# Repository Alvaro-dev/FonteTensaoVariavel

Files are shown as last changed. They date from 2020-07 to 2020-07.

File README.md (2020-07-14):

# Fonte Tensão 12V
Projeto de uma Fonte de Tensão Variável de 3V a 12V, desenvolvido para a disciplina de Eletrônica para Computação, ministrada pelo Professor Dr. Eduardo do Valle Simões
# Circuito Falstad
<a href = "http://tinyurl.com/yclddzmd"> Circuito Falstad</a>
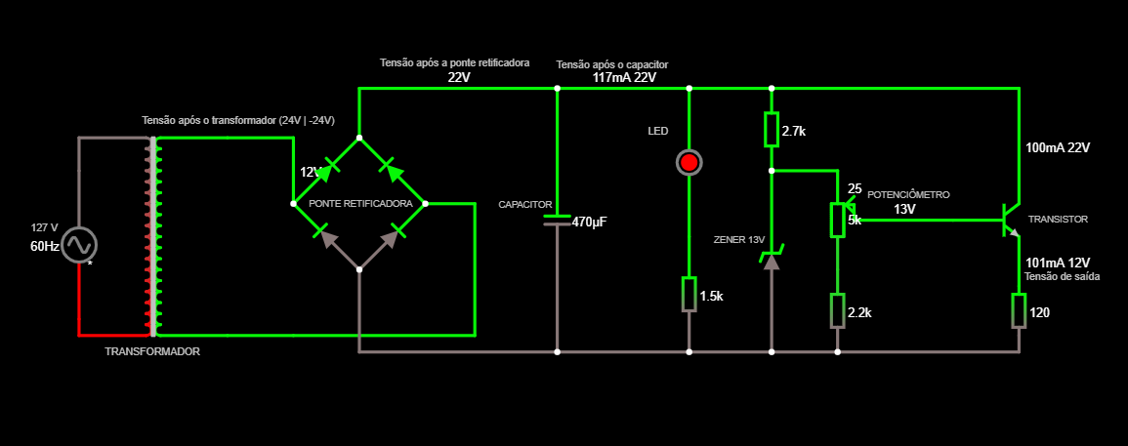
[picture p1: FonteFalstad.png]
Falstad

# Circuito EAGLE

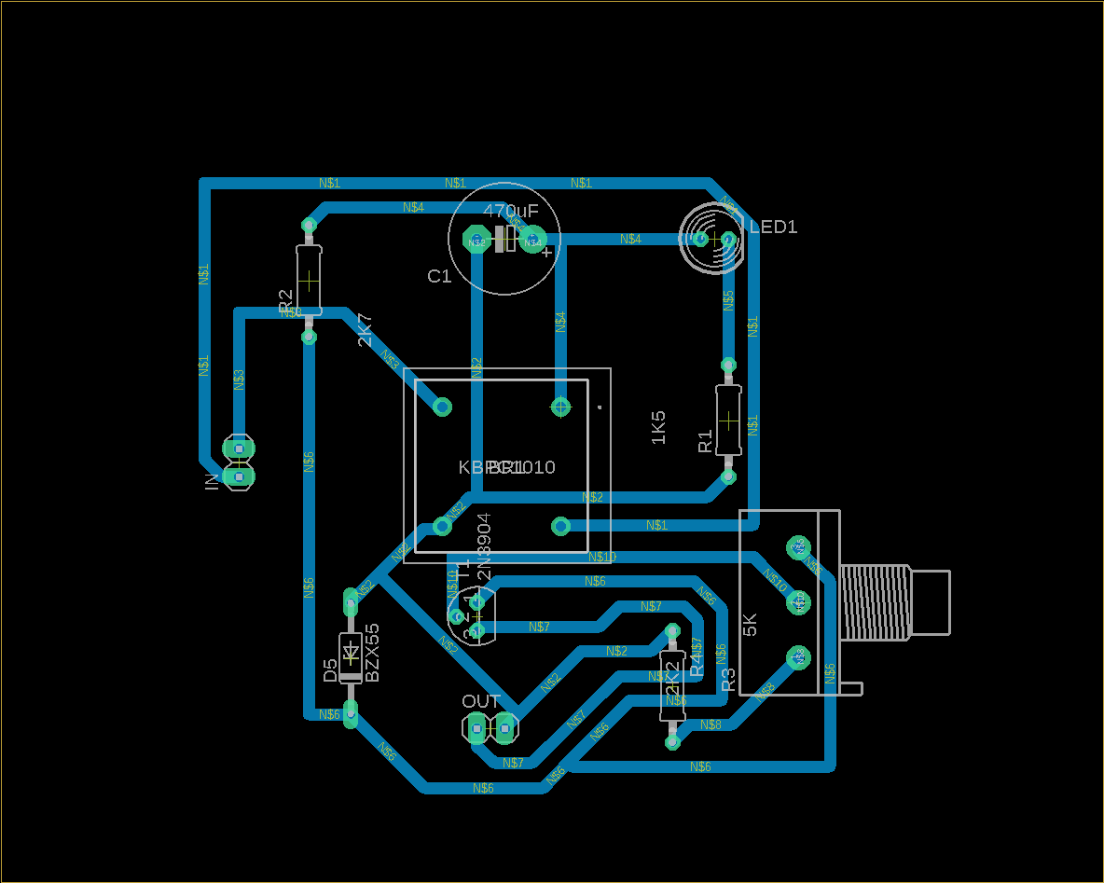
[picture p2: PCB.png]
PCB


<a href = "https://drive.google.com/file/d/1tgSCFVqVofuXs6VpP3hKhitnwWkWix8T/view?usp=sharing"> Vídeo Explicativo</a>

# Esquemático EAGLE
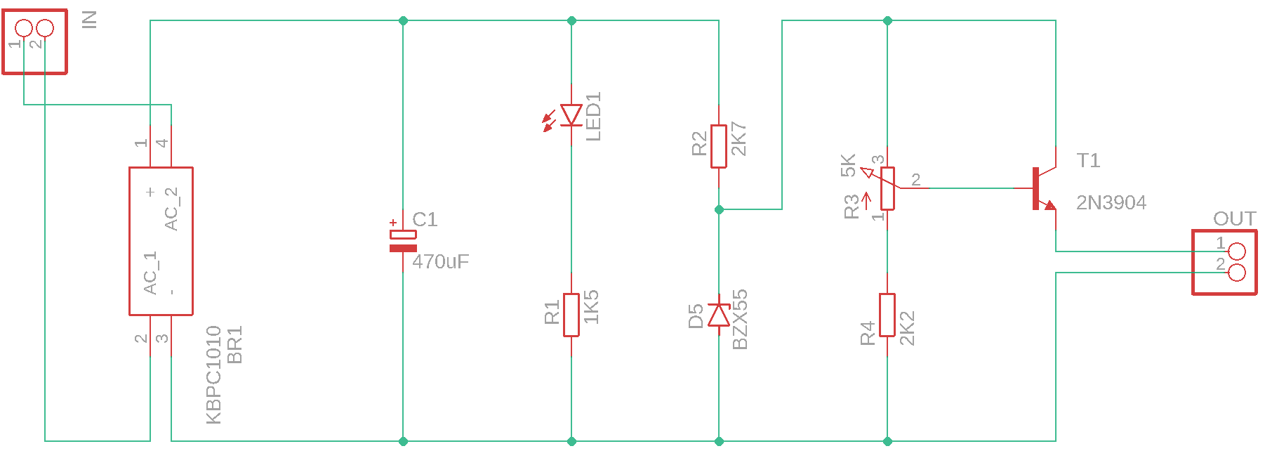
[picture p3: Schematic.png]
Schematic


## Conversor Corrente Alternada de Alta Tensão para Corrente Alternada de Baixa Tensão
Ao usar um transformador de 127V AC para 24V AC, com a razão descrita abaixo, a tensão do circuito, fica adequada aos componentes usados na fonte, que são mais sensíveis a valores altos de tensão e suas variações. Quando há variação de fluxo na corrente primária (127V), na parte secundária, é gerada uma corrente induzida com um potencial elétrico menor (24V). O intervalo de oscilação sai de 127V a -127V para 24V a -24V. A razão obtida na fórmula abaixo, auxiliou a resolução da problemática no Falstad, para conseguir ajustar a tensão secundária do transformador.

Transformador

## Conversor Corrente Alternada para Corrente Contínua
Como estamos lidando com uma corrente alternada (24V a -24V), é necessário uma estratégia para converter desse tipo de corrente elétrica para contínua, para o funcionamento adequado da fonte. Assim, usa-se uma ponte retificadora feita com diodos, cuja função é tornar a corrente unidirecional devido a propriedade do diodo, que permite o fluxo de corrente em apenas um sentido determinado. Por motivos de incompatibilidade com o Eagle e indisponibilidade no mercado, mas ainda avaliando a proporcionalidade do diodo/PCB, escolhemos a ponte retificadora KBPC1010 pois ela é compatível com o Eagle e está disponível na loja escolhida. 
Assim, a tensão na saída da ponte retificadora será uma unidirecional, porém instável para se usar dessa maneira na saída. Como a corrente nominal é, no máximo, de 1.205 A, usamos uma ponte retificadora de diodos que resiste a uma corrente de até 10 A, maior que o necessário, porém foi a ponte com menor especificação que encontramos na distribuidora.

## Filtragem de Corrente
A saída da ponte retificadora é instável, possuindo pequenas oscilações em sua voltagem, dessa forma forma será usado um capacitor conectado em paralelo com o output, com o objetivo de diminuir essas oscilações para a próxima parte do circuito. O objetivo de colcoar um capacitor, se baseia no fato do circuito precisar de tensão/corrente durante a parte na qual os valores de tais atributos estão baixos, necessitando que o capacitor se descarregue para manter uma margem confortável para o funcionamento geral do circuito.
O capacitor ao carregar e descarregar durante seu ciclo fornece um aumento linear da voltagem, filtrando o sinal e disponibilizando uma tensão mais estável. Dessa forma, escolhemos um capacitor de 470uF, valor ideal para manter uma corrente sem muitas oscilações.

Capacitor

## Regulador de Tensão
O Diodo Zener associado ao potenciômetro, conjuntamente com o Transistor NPN, permite que a tensão e corrente seja regulada e programada a partir de sua resistência variável.
- <b>Diodo Zener:</b> Ao ser conectado em paralelo, será responsável pela regulação da tensão máxima que será fornecida ao Potenciômetro. Esse componente atua filtrando a tensão somente quando for fornecido a ele uma tensão suficientemente maior do que a sua tensão nominal, 13V no caso deste projeto. Dessa forma, quando o Diodo Zener estiver ativo parte da corrente do circuito será absorvida e uma tensão 13V estável será fornecida ao Transistor. O Resistor R2value conectado será responsável por limitar a corrente que flui em direção ao Zener, tornando seguro o uso do modelo escolhido. Nota-se pelo simulador que há um pico de corrente de, aproximadamente, -1.5mA e que o Diodo está submetido a uma tensão de -13V, dissipando no máximo 19.5mW. Dessa forma, o componente escolhido (com especificações para 500mW) será suficiente.

- <b>Potenciômetro:</b> Resistor variável que permitirá regular a tensão elétrica de saída. Em conjunto com restante do circuito, o Potenciômetro foi devidamente projetado para fornecer uma tensão final no intervalo entre 3V e 12V, atendendo as especificações do projeto. Quando ajustado para uma resistência mínima, a tensão de saída será aproximadamente 12V. Analogamente, quando for regulado em sua resistência máxima a tensão fornecida será próxima de 3V. O Resistor R4 será responsável por regular a tensão fornecida ao transistor, adequando-a a 3V, quando o potenciômetro estiver com resistência máxima.

- <b>Transistor NPN:</b> Quando sobre ele é aplicada uma voltagem em sua base o Transistor passa a atuar em seu estado condutivo. Tem como papel, nesse circuito, amplificar a corrente, fornecendo ao circuito uma corrente, através do coletor, na ordem de 100 vezes maior do que a corrente base. Para atender ao requisitos do projeto (Fonte de Tensão com no máximo 100mA) foi escolhido um resistor de R120 para que a corrente final do circuito, quando regulado para 12V, permaneça nesse valor. Nota-se então que a corrente de base, e a corrente final possuirão os seguintes valores nos extremos:
  - Vout12
  - Vout3  

Vale notar que há no Transistor uma queda de tensão de aproximadamente 715 mV quando a tensão de base for 13V e de 678 mV quando a tensão da base for, aproximadamente, 4.6V. É preciso considerar essa queda de tensão uma vez que a tensão final do circuito será o resultado da tensão de base subtraída da queda de tensão no Transistor.

# Orçamento dos materiais usados
Tabela com os preços dos componentes
| Nome | Especificações | Preço |
| :---: | :---: | :---: |
| Transformador | Transformador Trafo 12V+12V 500mA – 110/220VAC | <a href = "https://www.baudaeletronica.com.br/transformador-trafo-12v-12v-500ma-110-220vac.html">R$ 22,23</a>|
| Resistor 1.5K | Resistor 1.5K 5% (1/4W) | <a href = "https://www.baudaeletronica.com.br/resistor-1k5-5-1-4w.html">R$ 0,08</a> |
| Resistor 2.7K | Resistor 2.7K 5% (1/4W) | <a href = "https://www.baudaeletronica.com.br/resistor-2k7-5-1-4w.html">R$ 0,08</a> |
| Resistor 2.2K | Resistor 2.2K 5% (1/4W) | <a href = "https://www.baudaeletronica.com.br/resistor-2k2-5-1-4w.html">R$ 0,08</a> |
| Resistor 120R | Resistor 120R 5% (1/4W) | <a href = "https://www.baudaeletronica.com.br/resistor-120r-5-1-4w.html">R$ 0,08</a> |
| LED | Led Difuso 5mm Vermelho | <a href = "https://www.eletrogate.com/led-difuso-5mm-vermelho">R$ 0,25</a> |
| Diodo Zener | Diodo Zener BZX55C [13V / 0.5W] | <a href = "https://www.baudaeletronica.com.br/diodo-zener-bzx55c-13v-0-5w.html">R$ 0,09</a> |
| Capacitor | Capacitor Eletrolítico 470uF / 35V | <a href = "https://www.baudaeletronica.com.br/capacitor-eletrolitico-470uf-35v.html">R$ 0,57</a> |
| Potenciômetro 5k | Potenciômetro Linear de 5K (5000Ω) | <a href = "https://www.baudaeletronica.com.br/potenciometro-linear-de-5k-5000.html">R$ 1,45</a> |
| Ponte Retificadora KBPC1010* | Ponte Retificadora de 10A | <a href = "https://www.baudaeletronica.com.br/ponte-retificadora-kbpc1010.html"> R$ 3,79  </a> |
| Transistor | Transistor NPN 2N3904 | <a href = "https://www.baudaeletronica.com.br/transistor-npn-2n3904.html">R$ 0,17</a> |
| Total |  | R$ 28,87 |

* Poderíamos ter usado componentes mais baratos, mas devido ao fato do software Eagle/Loja não possuirem os modelos modelos mais adequados, escolhemos esse.

# Agradecimentos
Queremos agradecer ao professor Dr Eduardo Simões pela oportunidade de fazer o trabalho com as retificações necessárias, conforme especificado. Esperamos que, no futuro, poderemos usufruir novamente de alguma disciplina ministrada pelo professor, em um contexto cujo aprendizado não seja à distância.

Queremos também agradecer aos criadores do website: https://componentsearchengine.com/ por nos disponibilizar as libraries do EAGLE de graça.

# Contribuição
Alvaro José Lopes - 10873365

Paulo Henrique de Souza Soares - 11884713

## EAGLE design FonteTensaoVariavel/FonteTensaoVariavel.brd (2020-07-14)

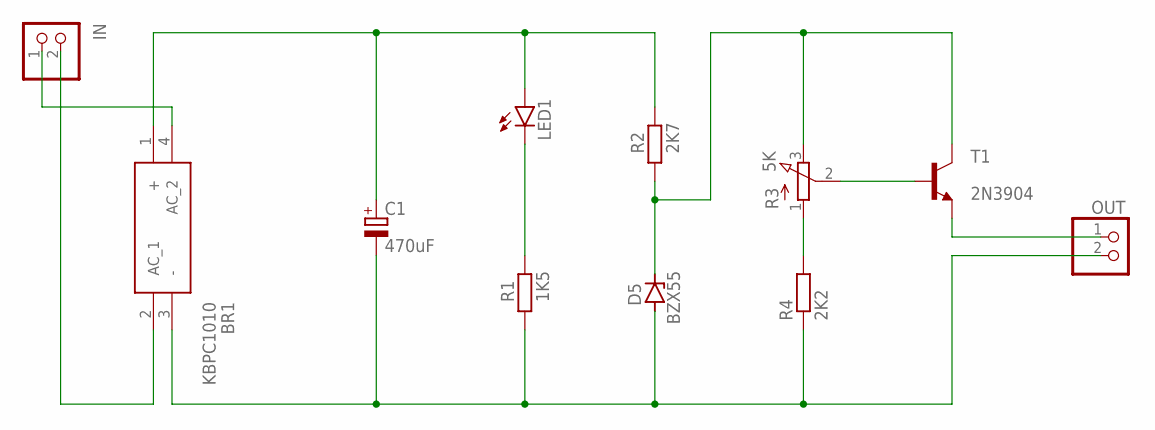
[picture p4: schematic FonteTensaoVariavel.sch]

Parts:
BR1: KBPC1010
C1: 470uF; E5-10,5
D5: BZX55; DO35Z10
IN: PINHD-1X2; 1X02
LED1: LED5MM
OUT: PINHD-1X2; 1X02
R1: 1K5; 0207/10
R2: 2K7; 0207/10
R3: 5K; 3RP/1610N
R4: 2K2; 0207/10
T1: 2N3904; TO92

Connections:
unnamed: BR1.4 (AC_2), IN.1
unnamed: BR1.3 (-), C1.-, D5.A, OUT.2, R1.1, R4.1
unnamed: BR1.2 (AC_1), IN.2
unnamed: BR1.1 (+), C1.+, LED1.A, R2.2
unnamed: LED1.K (C), R1.2
unnamed: D5.C, R2.1, R3.3 (E), T1.1 (C)
unnamed: OUT.1, T1.3 (E)
unnamed: R3.1 (A), R4.2
unnamed: R3.2 (S), T1.2 (B)

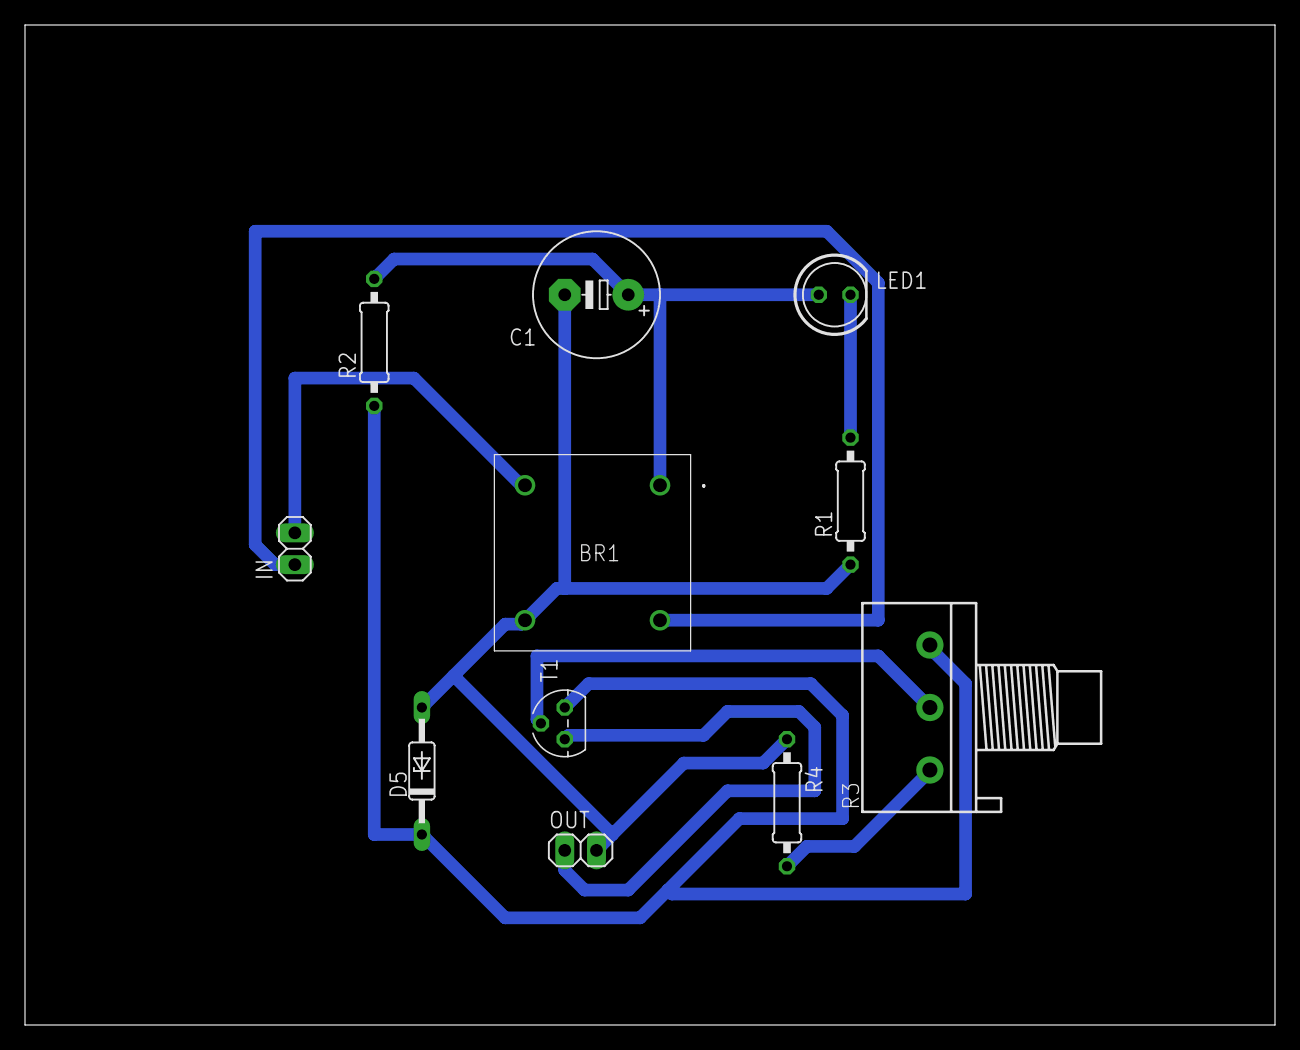
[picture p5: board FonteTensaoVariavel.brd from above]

Board: 2 copper layers, 100.0 x 80.0 mm, 11 parts (0 on the bottom side), 9 nets.
